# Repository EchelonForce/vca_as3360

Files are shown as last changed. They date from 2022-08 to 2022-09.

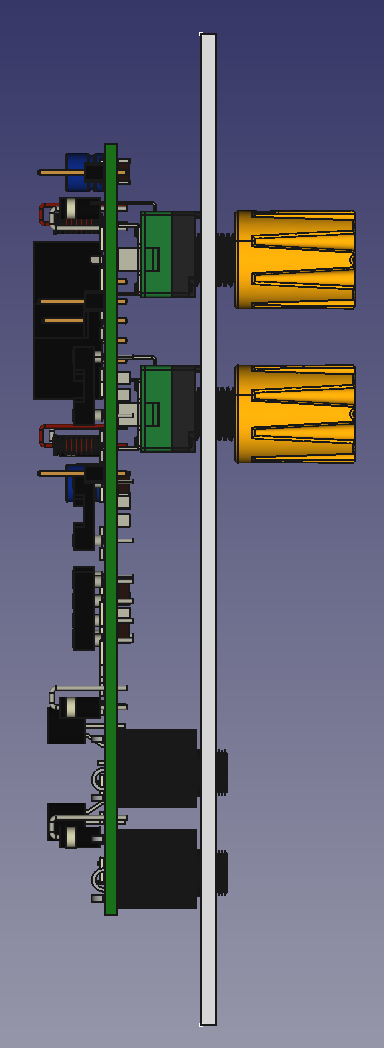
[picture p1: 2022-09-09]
front_panel_v1/render3.png

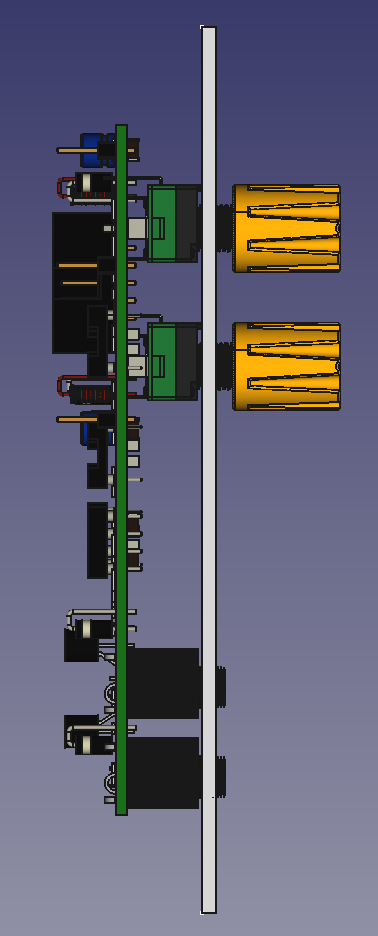
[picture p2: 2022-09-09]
dual_front_panel_v1/render3.png

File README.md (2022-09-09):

# Eurorack VCA AS3360

This is a design for a eurorack VCA using the AS3360 Dual VCA chip.

Full writeup here: https://www.robotdialogs.com/2022/09/eurorack-vca-module-as3360.html

This work is licensed under a Creative Commons Attribution-NonCommercial-ShareAlike 4.0 International License. https://creativecommons.org/licenses/by-nc-sa/4.0/

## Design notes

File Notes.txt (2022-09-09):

Useful reference
https://www.lookmumnocomputer.com/1181-dual-vca
http://www.alfarzpp.lv/eng/sc/AS3360.pdf

v1 testing
First build: 
CV a little off:
  pots seem to exercise full range but a lot of the pot range is wasted?
  CV 0-5V instead of 0-10V?
  measured at the pin on the as3360, the CV 0-10 goes 0-2V as designed, but the data sheet has max gain listed at 1.7-1.8V, so 2V is a bit too high. Need to adjust dividers into U3 because the non-inverting buffer has gain of 2 I didn't account for...I think I want about 1.6V at the AS3360 so I'll shoot for 0.8V at the input of U3, so 390k/33k...looks good.

v1 to v2 changes
used 33k instead of 50k
used 390k instead of 400k
U3 is label tl074 but it should be lm358, swapped with U1 which is also wrong.

May need to swap for smd tl072's

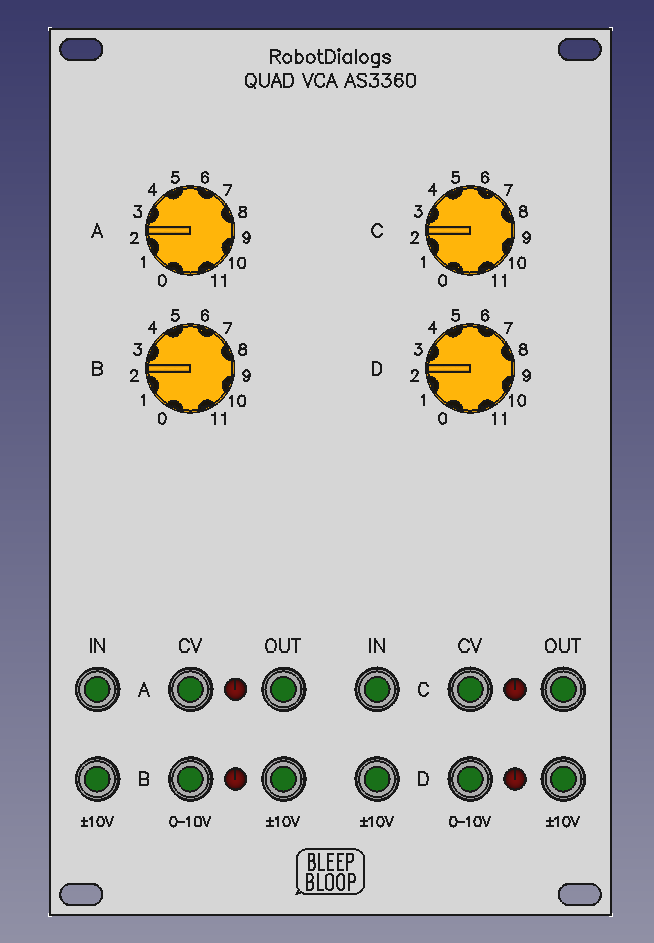
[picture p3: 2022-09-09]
dual_front_panel_v1/render1.png

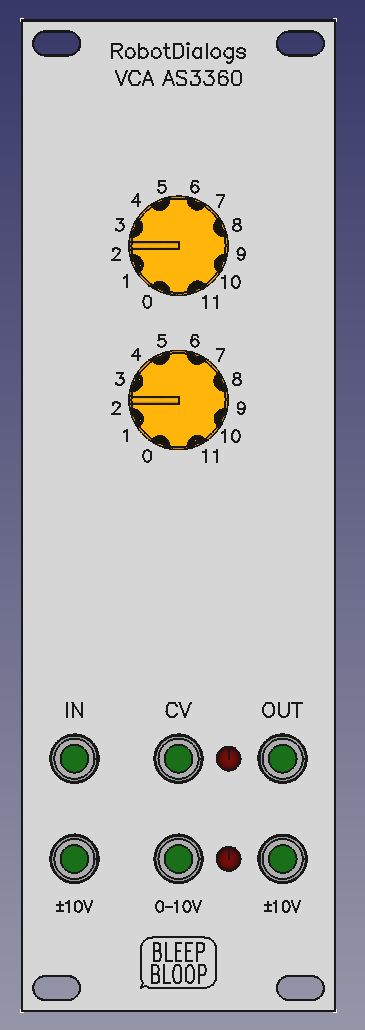
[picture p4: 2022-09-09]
front_panel_v1/render1.png

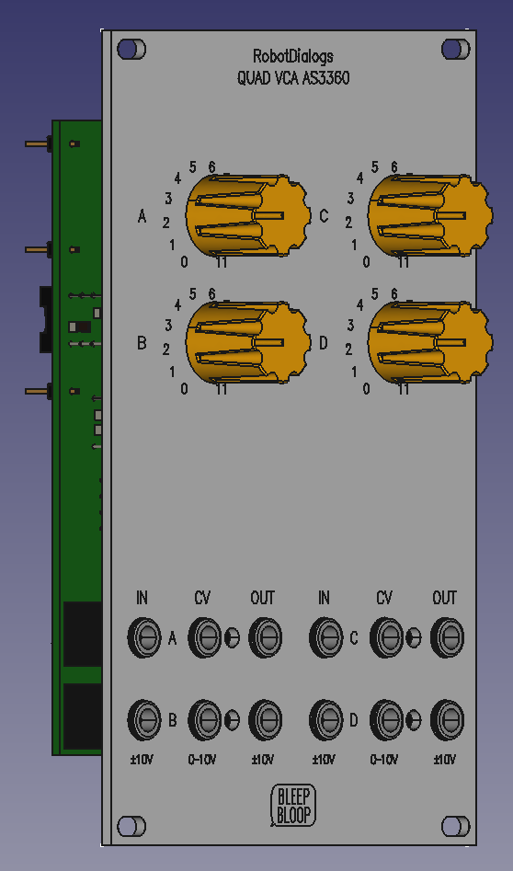
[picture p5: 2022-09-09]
dual_front_panel_v1/render2.png

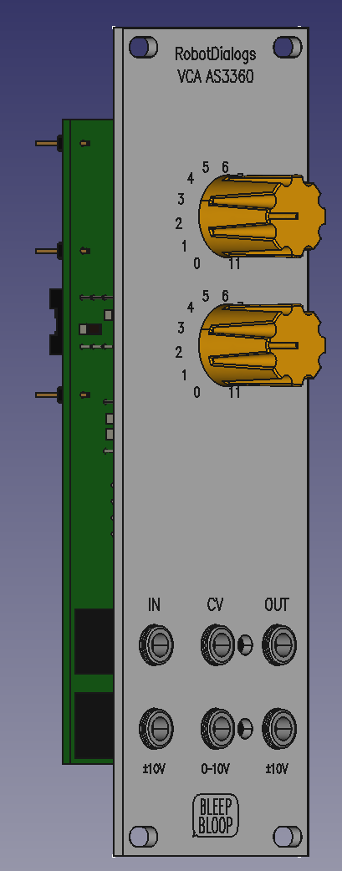
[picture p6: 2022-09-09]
front_panel_v1/render2.png

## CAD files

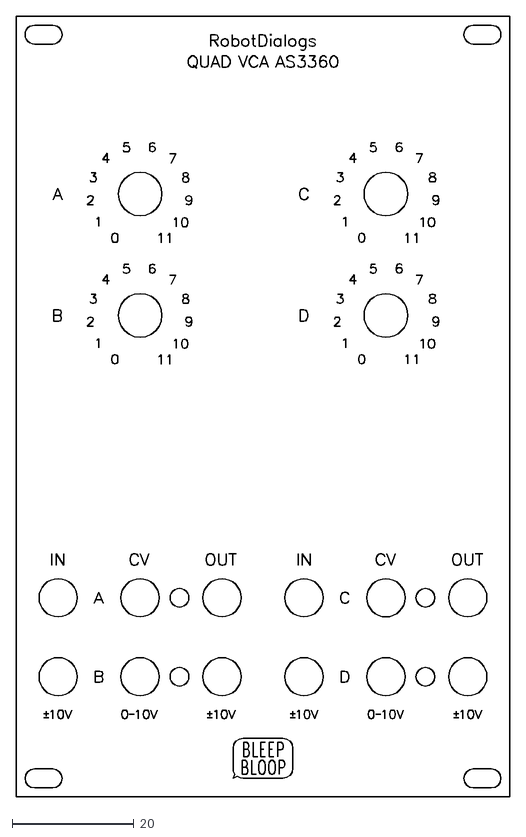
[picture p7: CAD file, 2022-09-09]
dual_front_panel_v1/dual_vca_as3360_v1_front_panel_v1_engraving.dxf
81.2 x 128.4

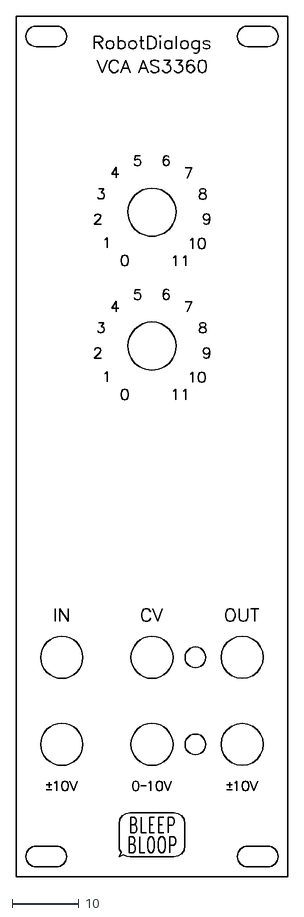
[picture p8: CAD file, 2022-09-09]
front_panel_v1/vca_as3360_v1_front_panel_v1_engraving.dxf
40.5 x 128.4

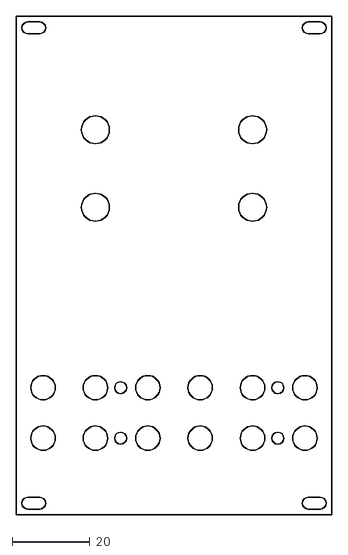
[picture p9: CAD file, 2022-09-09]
dual_front_panel_v1/dual_vca_as3360_v1_front_panel_v1_no_engraving.dxf
81.3 x 128.5

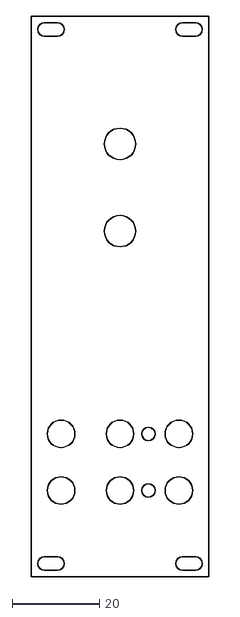
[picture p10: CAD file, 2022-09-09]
front_panel_v1/vca_as3360_v1_front_panel_v1_no_engraving.dxf
40.6 x 128.5

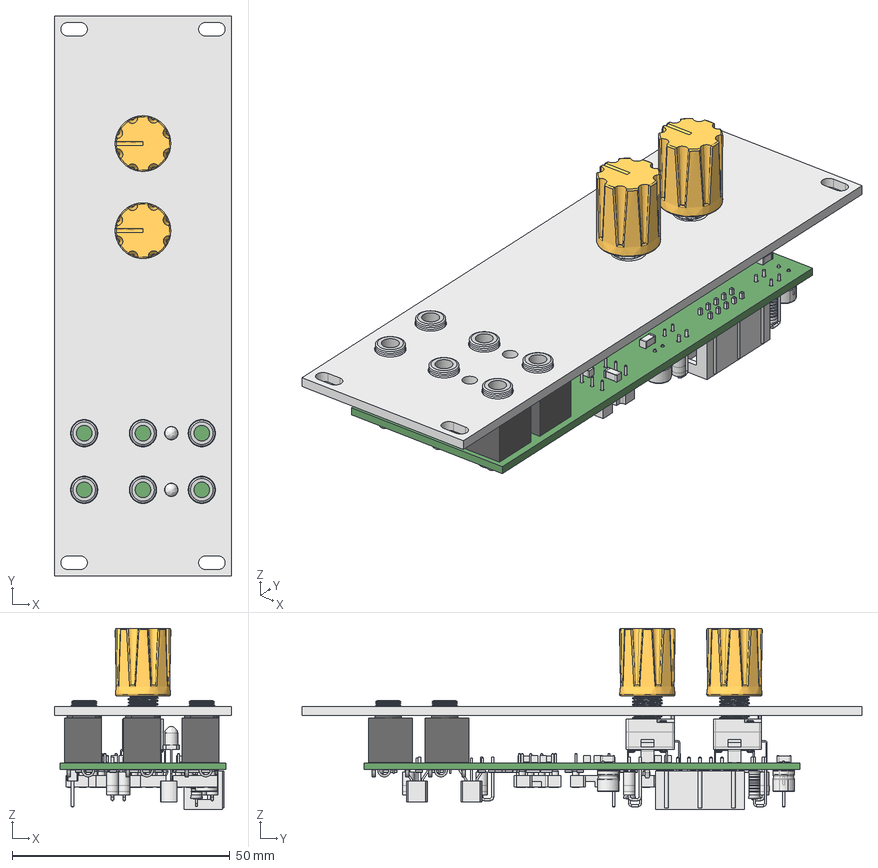
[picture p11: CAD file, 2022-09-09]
front_panel_v1/vca_as3360_v1_front_panel_v1.FCStd
40.6 x 128.5 x 41.6 mm
vca_as3360_v1 PCB

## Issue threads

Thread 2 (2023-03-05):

opamps and diodes confusion

KeLaiFu, 2023-03-05:
I've been working with your schematic and layout to build a smaller 4HP version, and just noticed a few things from your notes which I am unsure about.
Firstly, you mention the opamps being mixed up in V1. I am a little unsure if this means I need to switch them around as there only appears to be a v1, so could you clarify which of the 3 should be a 358?

Second, any suggestions for the diode value needed for D1/2/3/4

EchelonForce, 2023-03-05:
The v1 schematic is the only one for now, I usually take notes in anticipation of a v2, so it typically says changes for v2 even when I haven't started a v2.

The schematic is correct with regard to the op-amps. The problem I noted was that the labels I added on the PCB's silkscreen were placed next to the wrong footprints, realistically the TL072 and LM358 are pretty interchangeable in this. I usually use LM358s on CV inputs and TL07x's on audio pathways.

I used 1N4001's for the diodes D2,D3,D4,D6 (and generic red LEDs for D1/D5).

I recently built a bunch of these and have reduced R19 and R20 to 24k, and left R29 and R24 as 333k as in the notes. This reduced clipping and improved the knob range, the allowed voltage on the Linear CV pin on the AS3360 is larger than the input one should use in practice. I think mine ended up somewhere around 0:1.8V input (at the chip) for full range.

KeLaiFu, 2023-03-06:
Thanks for the reply. I have changed the layout to SMD, so the silkscreen issues won't effect me. Glad the 400k resistors won't be needed too, it was one of the few values I don't have in my stash and after ordering some, I received 402k anyway so fingers crossed I have some 333k.

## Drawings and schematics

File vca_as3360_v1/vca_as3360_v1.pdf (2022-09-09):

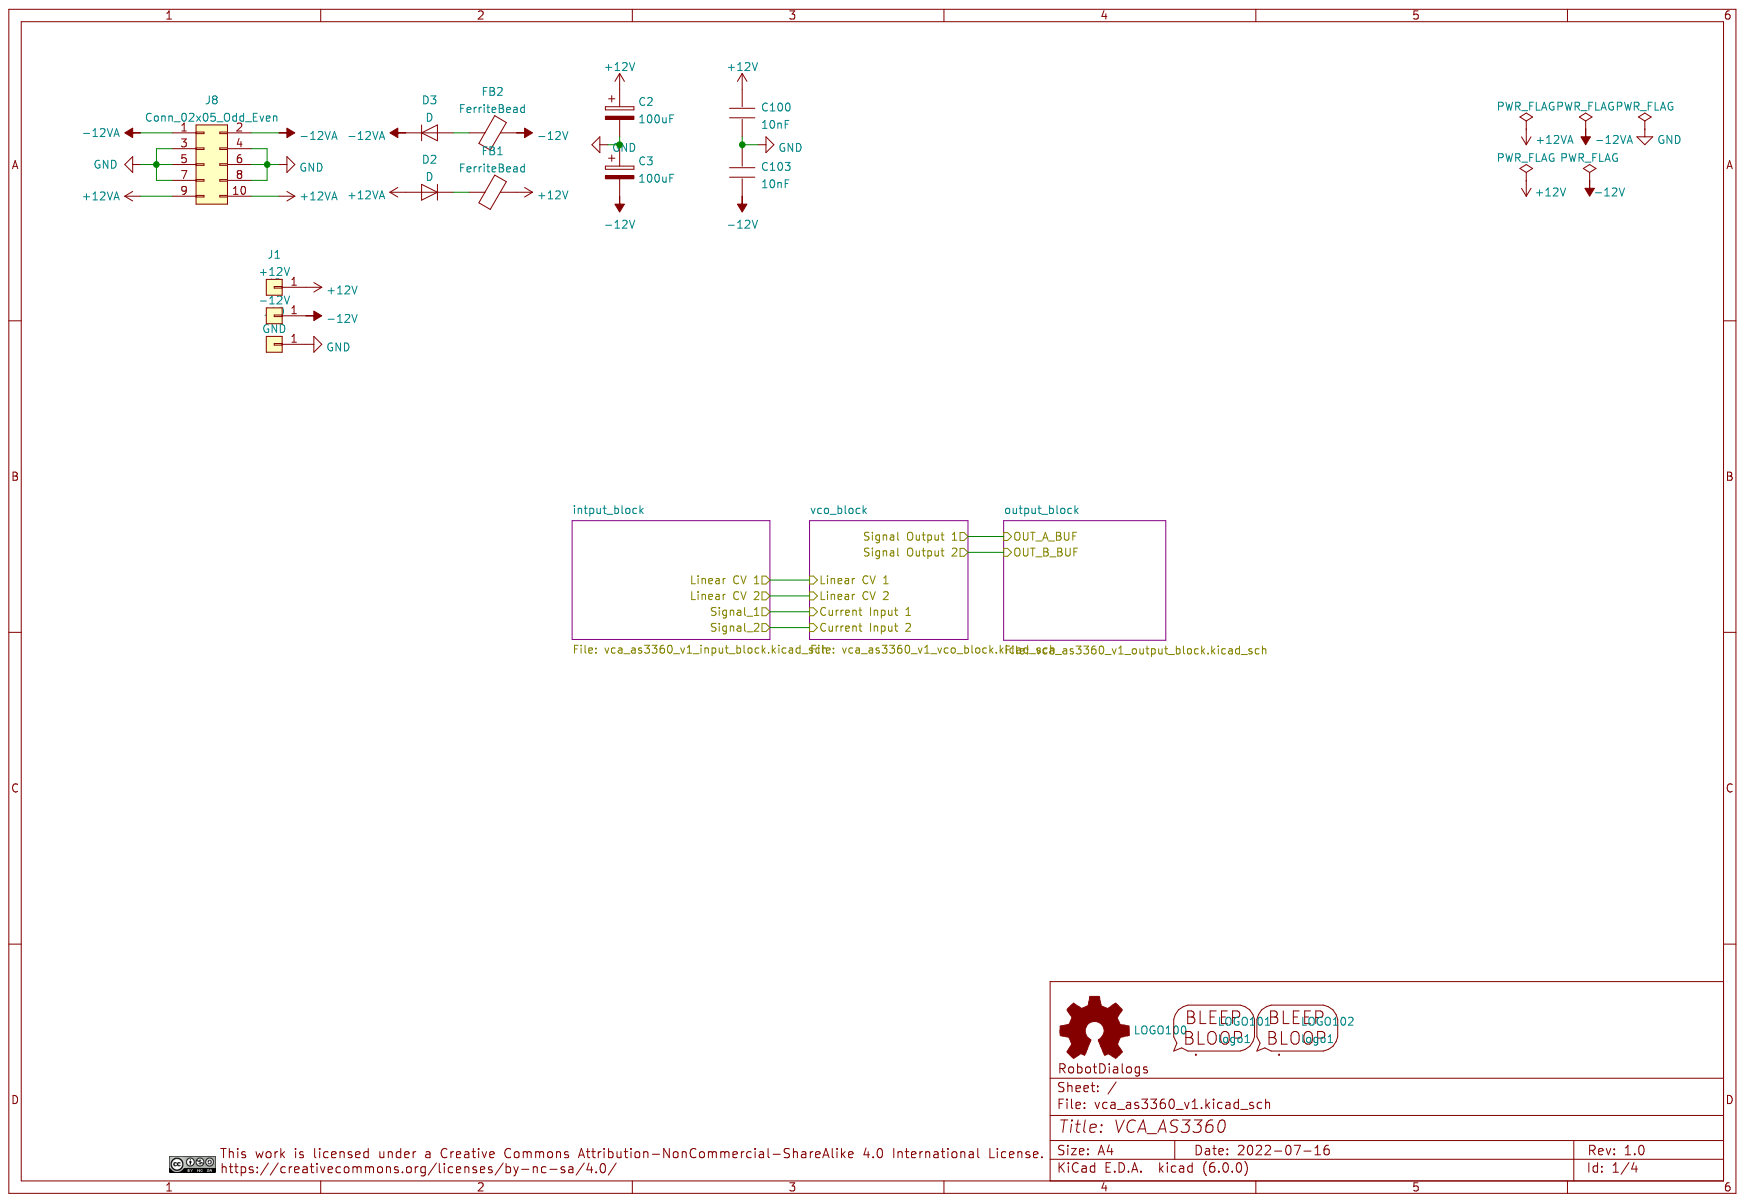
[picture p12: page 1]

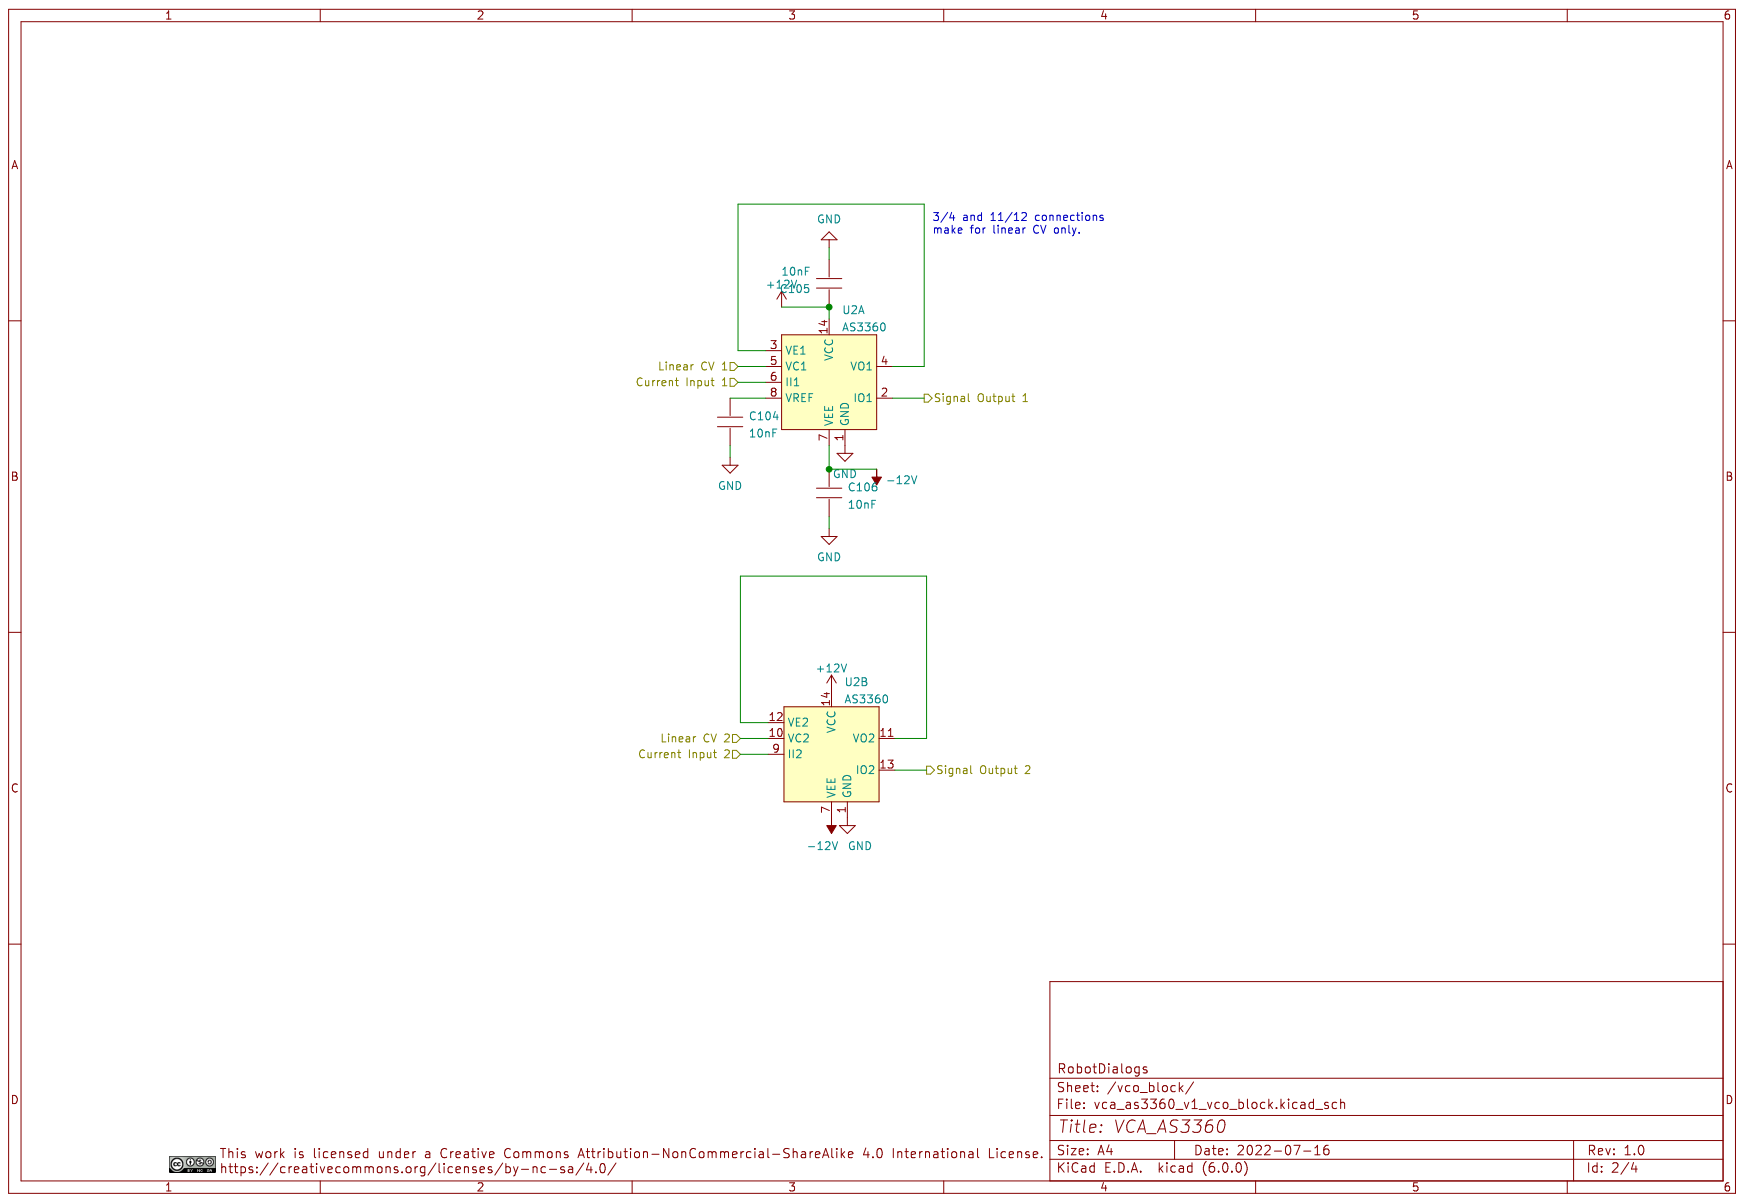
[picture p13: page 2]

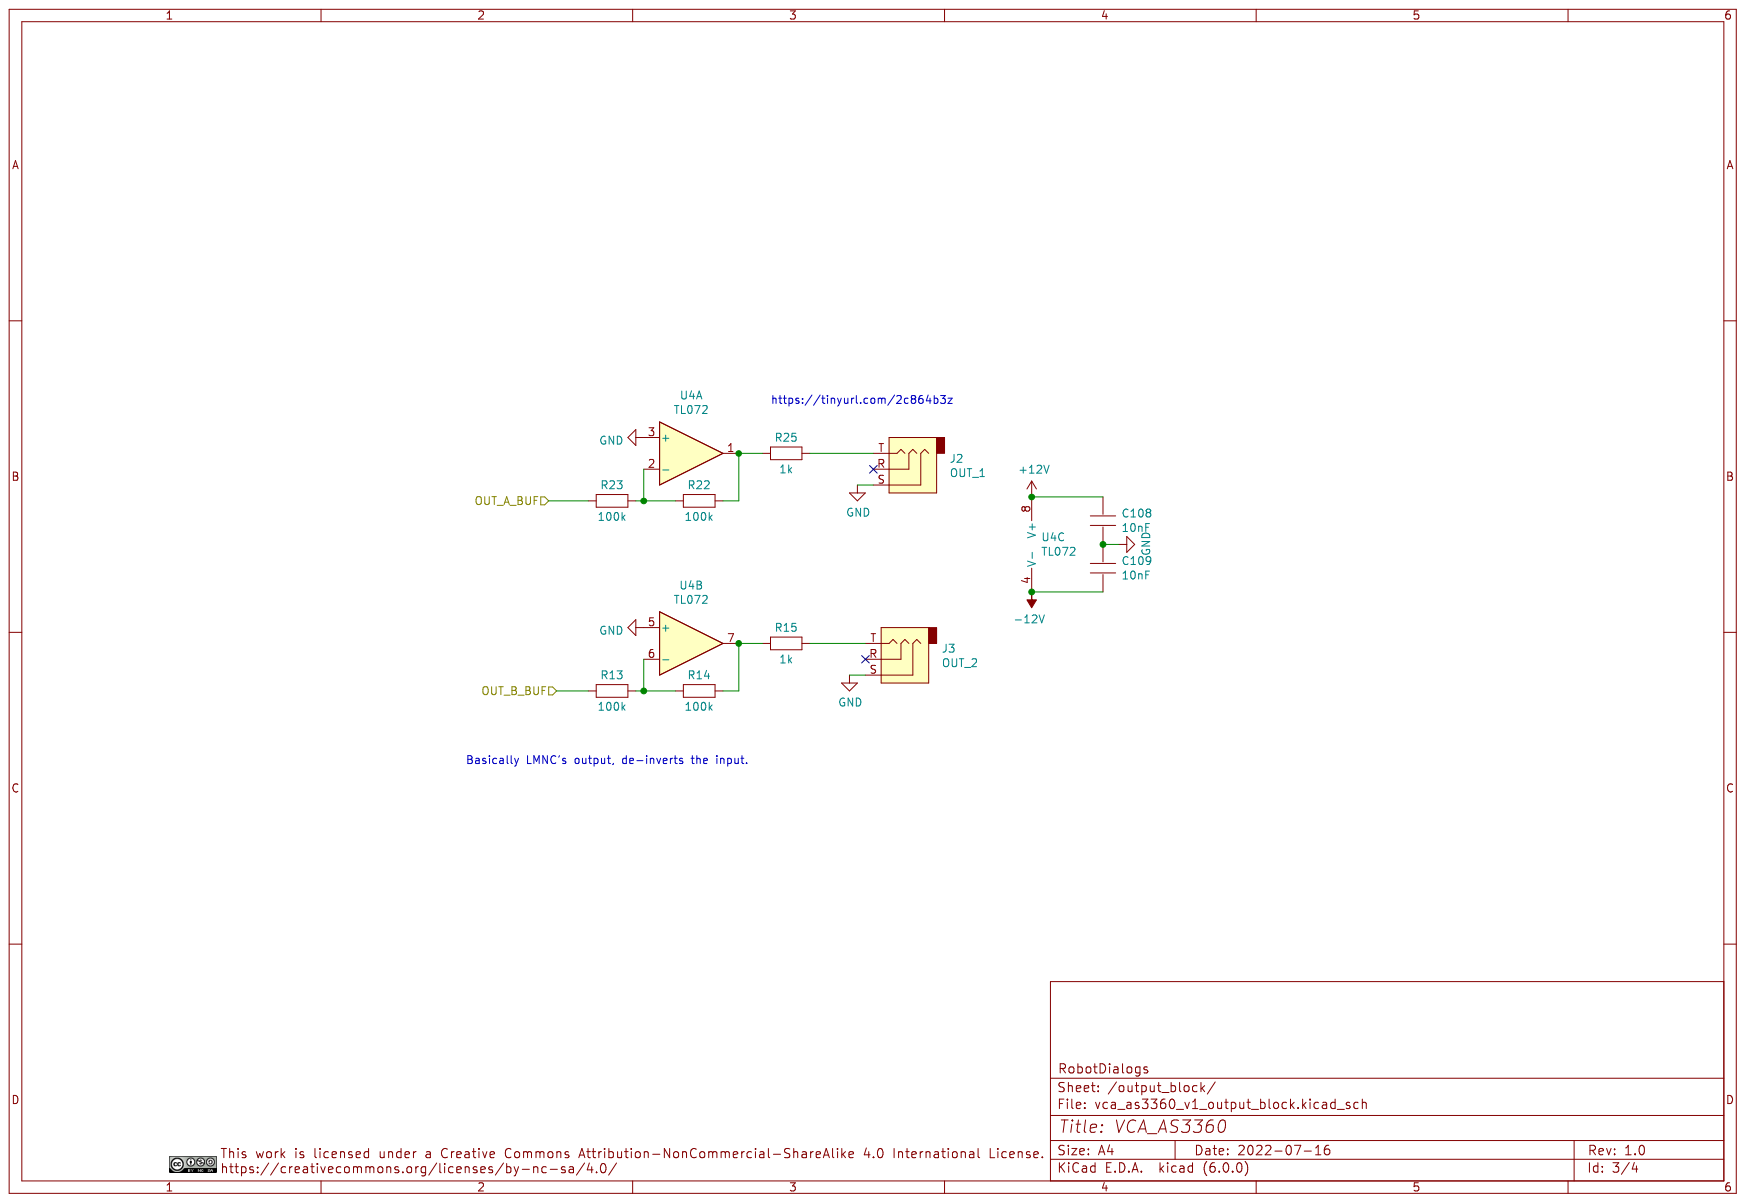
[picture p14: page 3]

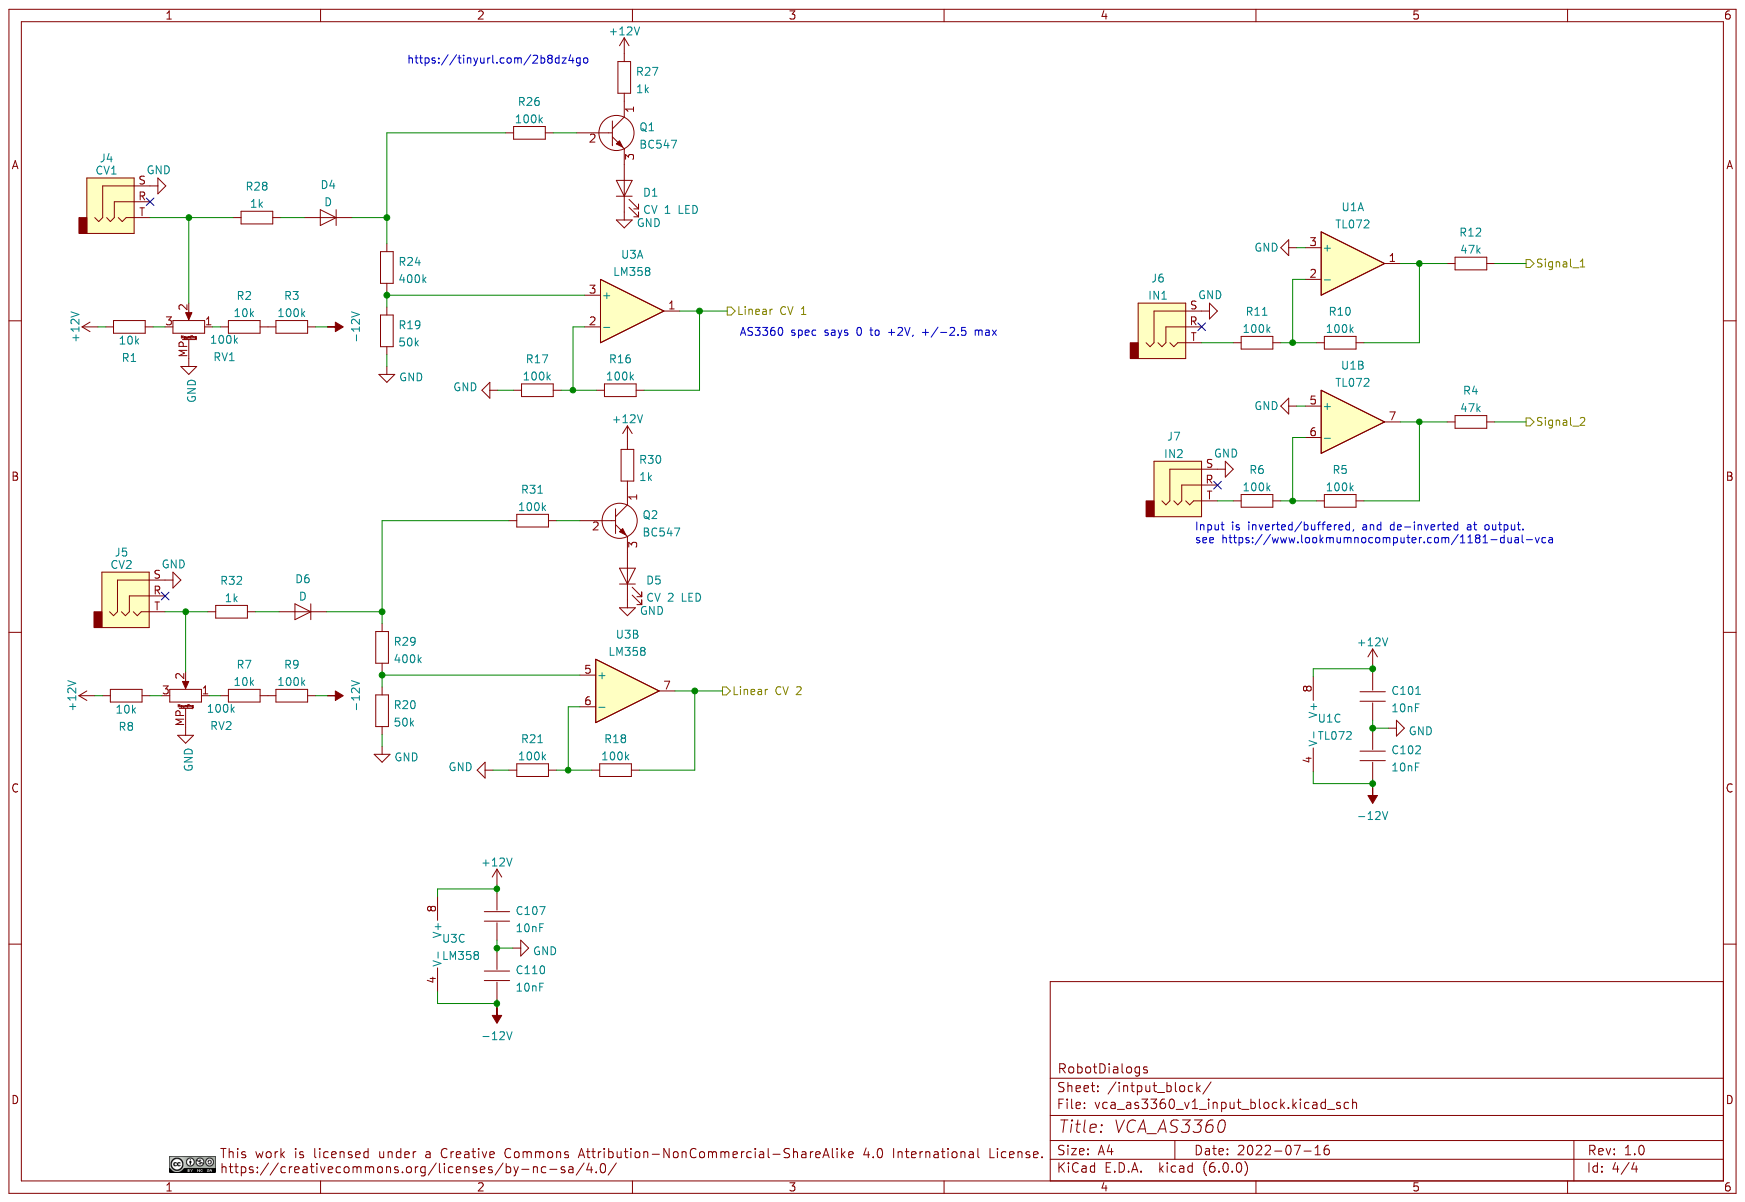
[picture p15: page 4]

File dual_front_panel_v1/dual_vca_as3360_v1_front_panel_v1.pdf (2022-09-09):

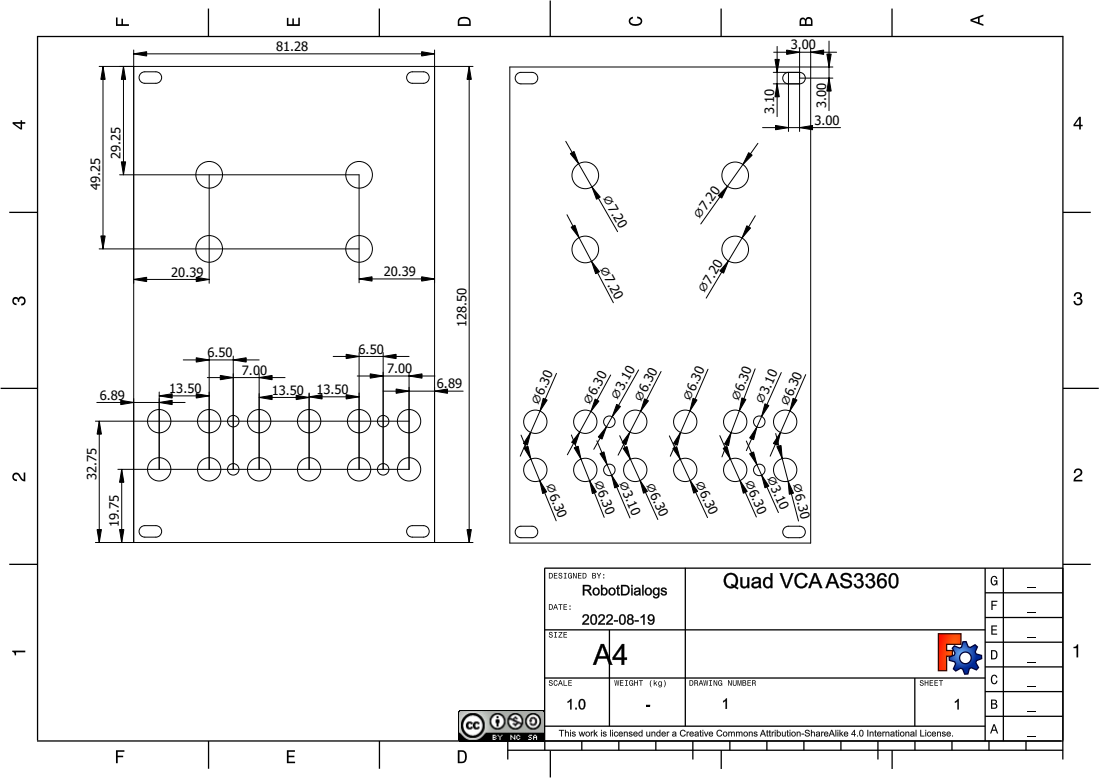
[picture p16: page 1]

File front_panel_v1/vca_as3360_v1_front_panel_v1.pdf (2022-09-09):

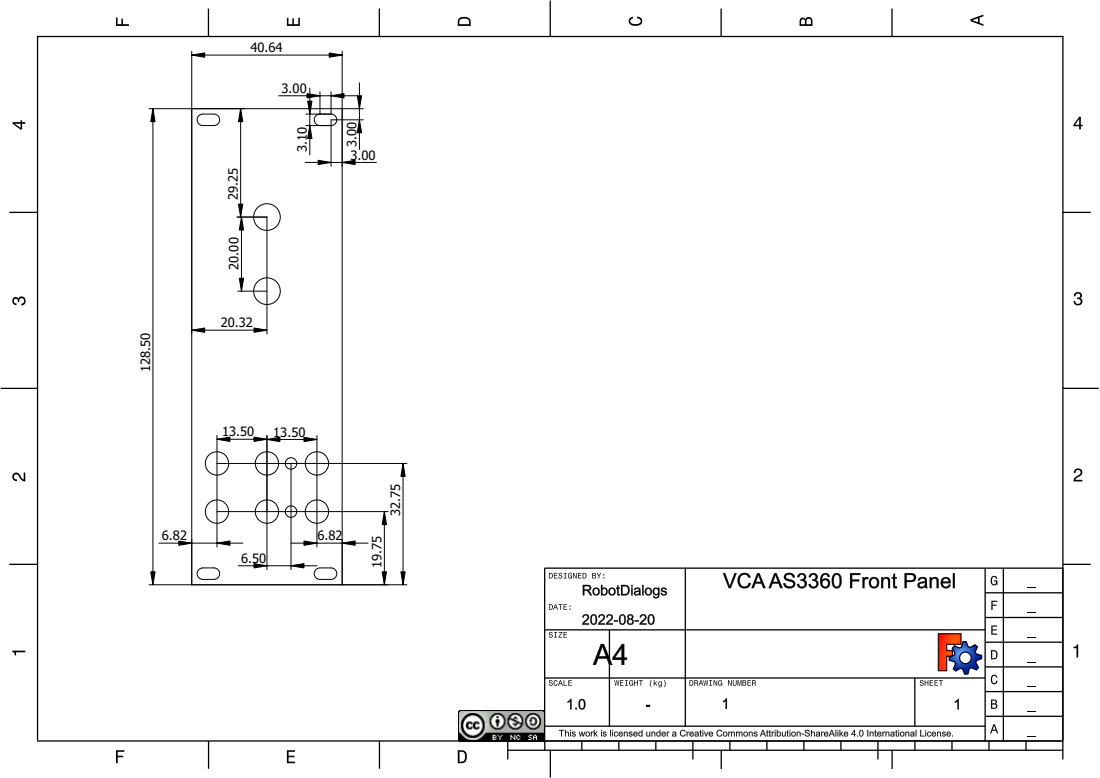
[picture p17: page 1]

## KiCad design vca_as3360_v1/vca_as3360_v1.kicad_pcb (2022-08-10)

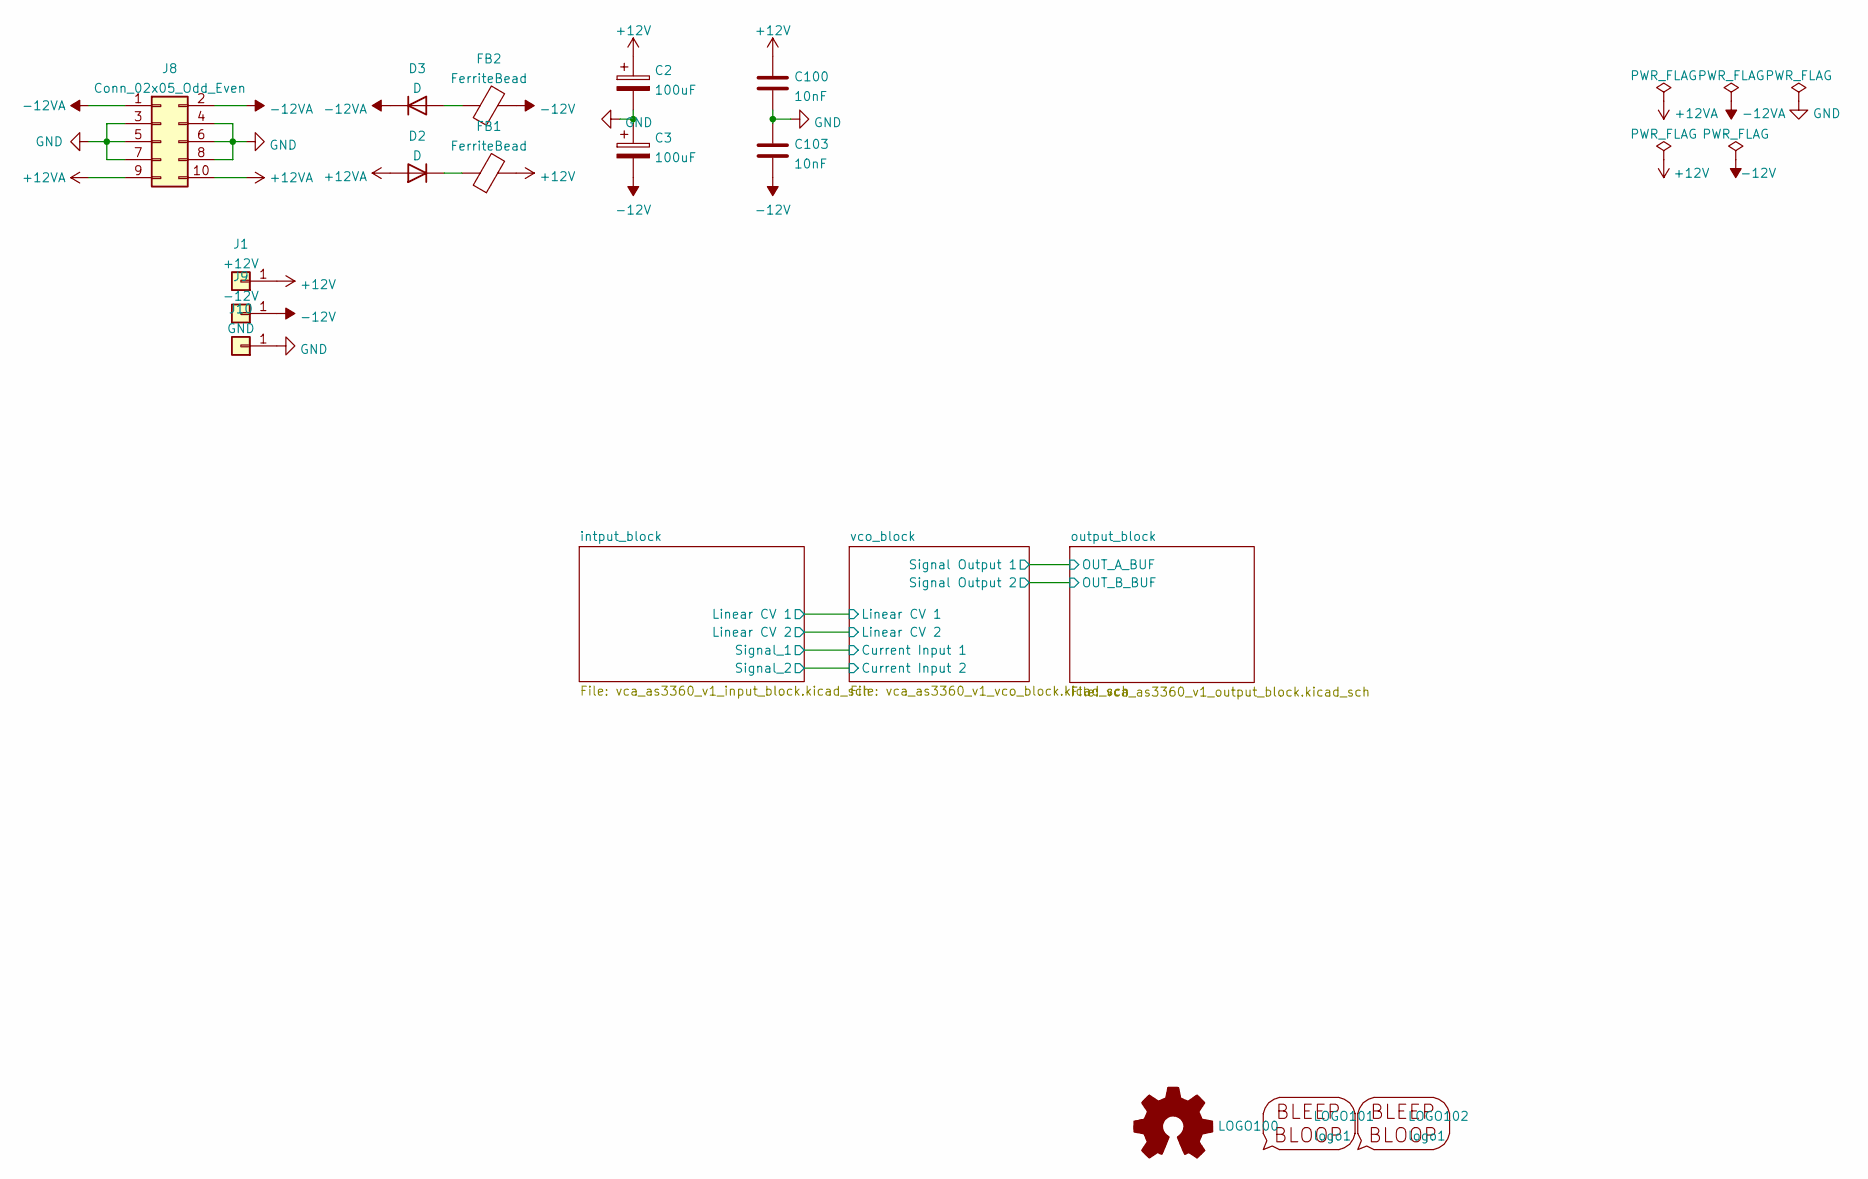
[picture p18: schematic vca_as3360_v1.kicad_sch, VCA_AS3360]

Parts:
C2, C3: 100uF; CP_Radial_D5.0mm_P2.50mm
C100, C103: 10nF; C_1206_3216Metric_Pad1.33x1.80mm_HandSolder
D2, D3: D; D_A-405_P2.54mm_Vertical_KathodeUp
FB1, FB2: FerriteBead; L_Axial_L6.6mm_D2.7mm_P2.54mm_Vertical_Vishay_IM-2
J1: +12V; PinHeader_1x01_P2.54mm_Vertical
J8: Conn_02x05_Odd_Even; IDC-Header_2x05_P2.54mm_Vertical
J9: -12V; PinHeader_1x01_P2.54mm_Vertical
J10: GND; PinHeader_1x01_P2.54mm_Vertical
LOGO100: Logo_Open_Hardware_Small; OSHW-Symbol_6.7x6mm_SilkScreen
LOGO101: logo1; Logo1
LOGO102: logo1; Logo2

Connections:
+12V: C2.1, C100.1, FB1.2, J1.1; also elsewhere on the board
+12VA: D2.2 (A), J8.9, J8.10
-12V: C3.2, C103.2, FB2.2, J9.1; also elsewhere on the board
-12VA: D3.1 (K), J8.1, J8.2
GND: C2.2, C3.1, C100.2, C103.1, J8.3, J8.4, J8.5, J8.6, J8.7, J8.8, J10.1; also elsewhere on the board
unnamed: D2.1 (K), FB1.1
unnamed: D3.2 (A), FB2.1

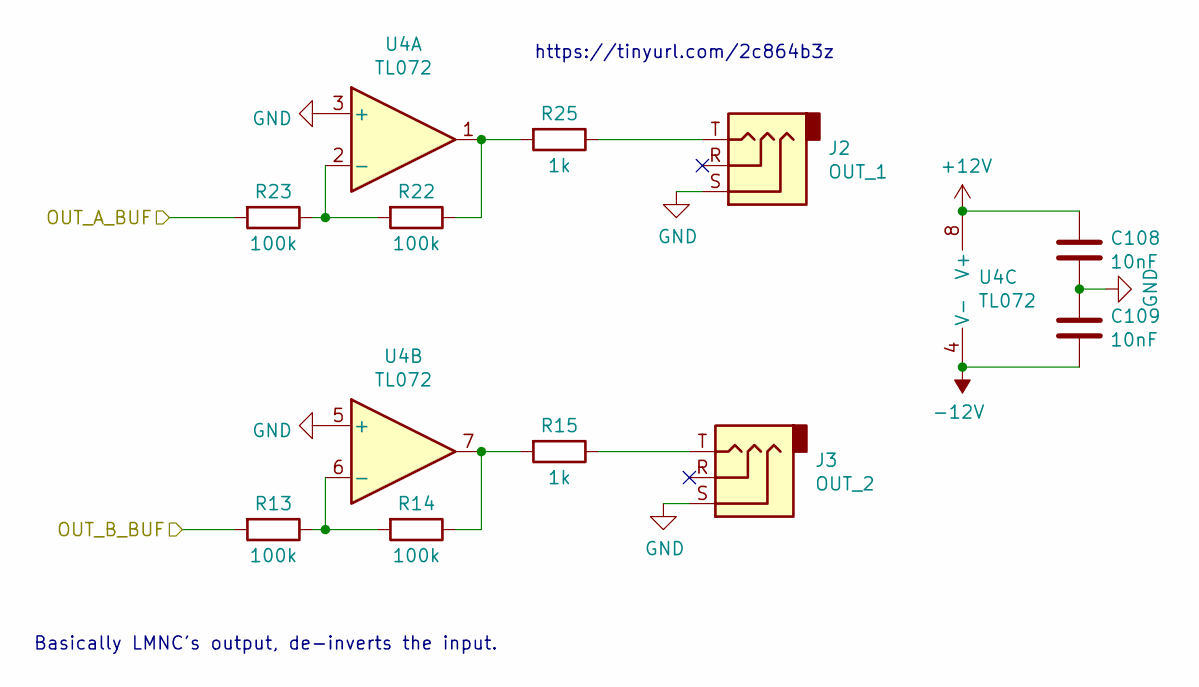
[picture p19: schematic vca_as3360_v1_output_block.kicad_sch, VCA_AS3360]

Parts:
C108, C109: 10nF; C_1206_3216Metric_Pad1.33x1.80mm_HandSolder
J2: OUT_1; Jack_3.5mm_MJ-355W_Vertical
J3: OUT_2; Jack_3.5mm_MJ-355W_Vertical
R13, R14, R22, R23: 100k; R_1206_3216Metric_Pad1.30x1.75mm_HandSolder
R15, R25: 1k; R_1206_3216Metric_Pad1.30x1.75mm_HandSolder
U4: TL072; DIP-8_W7.62mm_Socket_LongPads

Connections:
+12V: C108.2, U4.8 (V+); also elsewhere on the board
-12V: C109.1, U4.4 (V-); also elsewhere on the board
/output_block/OUT_A_BUF: R23.2; also elsewhere on the board
/output_block/OUT_B_BUF: R13.2; also elsewhere on the board
GND: C108.1, C109.2, J2.S, J3.S, U4.3 (+), U4.5 (+); also elsewhere on the board
unnamed: J2.T, R25.1
unnamed: J3.T, R15.1
unnamed: R14.1, R15.2, U4.7
unnamed: R13.1, R14.2, U4.6 (-)
unnamed: R22.2, R23.1, U4.2 (-)
unnamed: R22.1, R25.2, U4.1

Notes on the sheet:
Basically LMNC's output, de-inverts the input.
https://tinyurl.com/2c864b3z

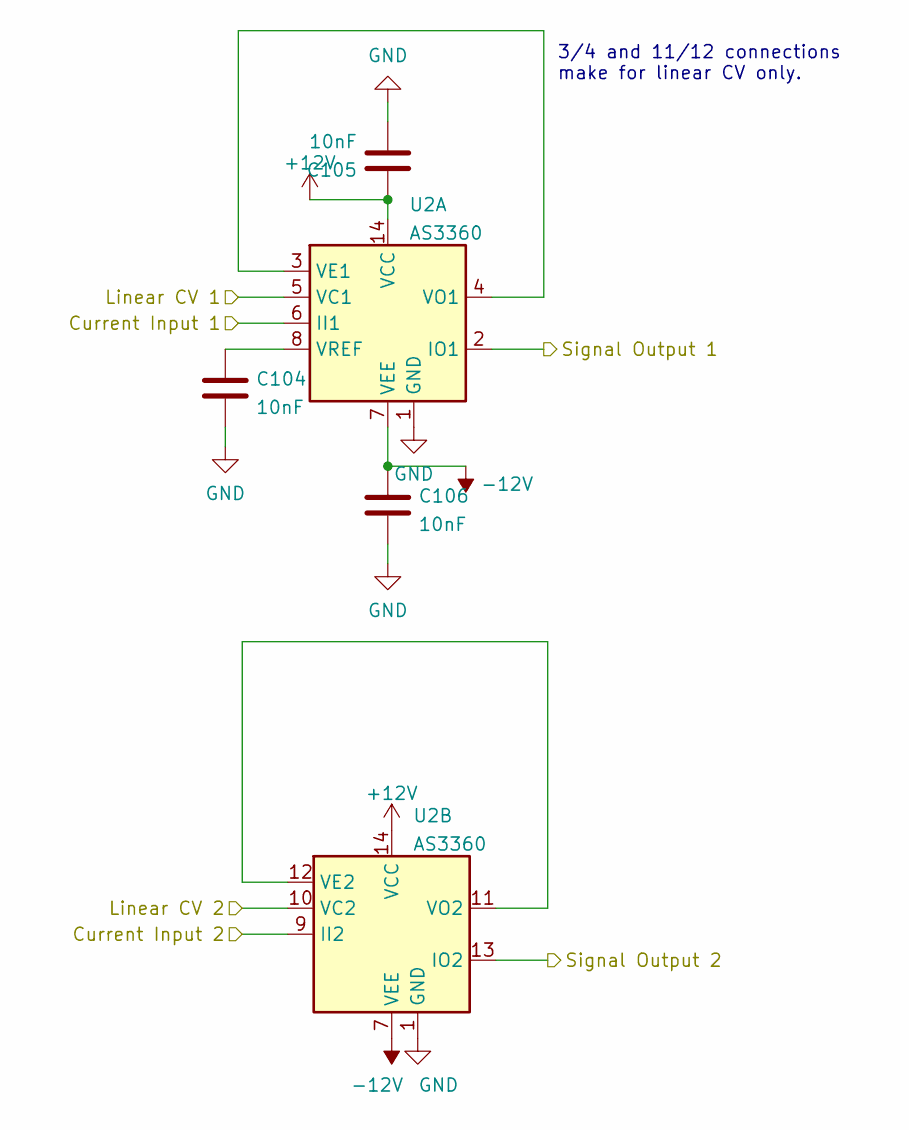
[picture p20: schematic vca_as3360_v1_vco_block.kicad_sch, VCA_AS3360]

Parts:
C104, C105, C106: 10nF; C_1206_3216Metric_Pad1.33x1.80mm_HandSolder
U2: AS3360; DIP-14_W7.62mm_Socket_LongPads

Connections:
+12V: C105.1, U2.14 (VCC); also elsewhere on the board
-12V: C106.1, U2.7 (VEE); also elsewhere on the board
/intput_block/Linear CV 1: U2.5 (VC1); also elsewhere on the board
/intput_block/Linear CV 2: U2.10 (VC2); also elsewhere on the board
/intput_block/Signal_1: U2.6 (II1); also elsewhere on the board
/intput_block/Signal_2: U2.9 (II2); also elsewhere on the board
/output_block/OUT_A_BUF: U2.2 (IO1); also elsewhere on the board
/output_block/OUT_B_BUF: U2.13 (IO2); also elsewhere on the board
GND: C104.2, C105.2, C106.2, U2.1 (GND); also elsewhere on the board
unnamed: C104.1, U2.8 (VREF)
unnamed: U2.3 (VE1), U2.4 (VO1)
unnamed: U2.11 (VO2), U2.12 (VE2)

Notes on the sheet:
3/4 and 11/12 connections make for linear CV only.

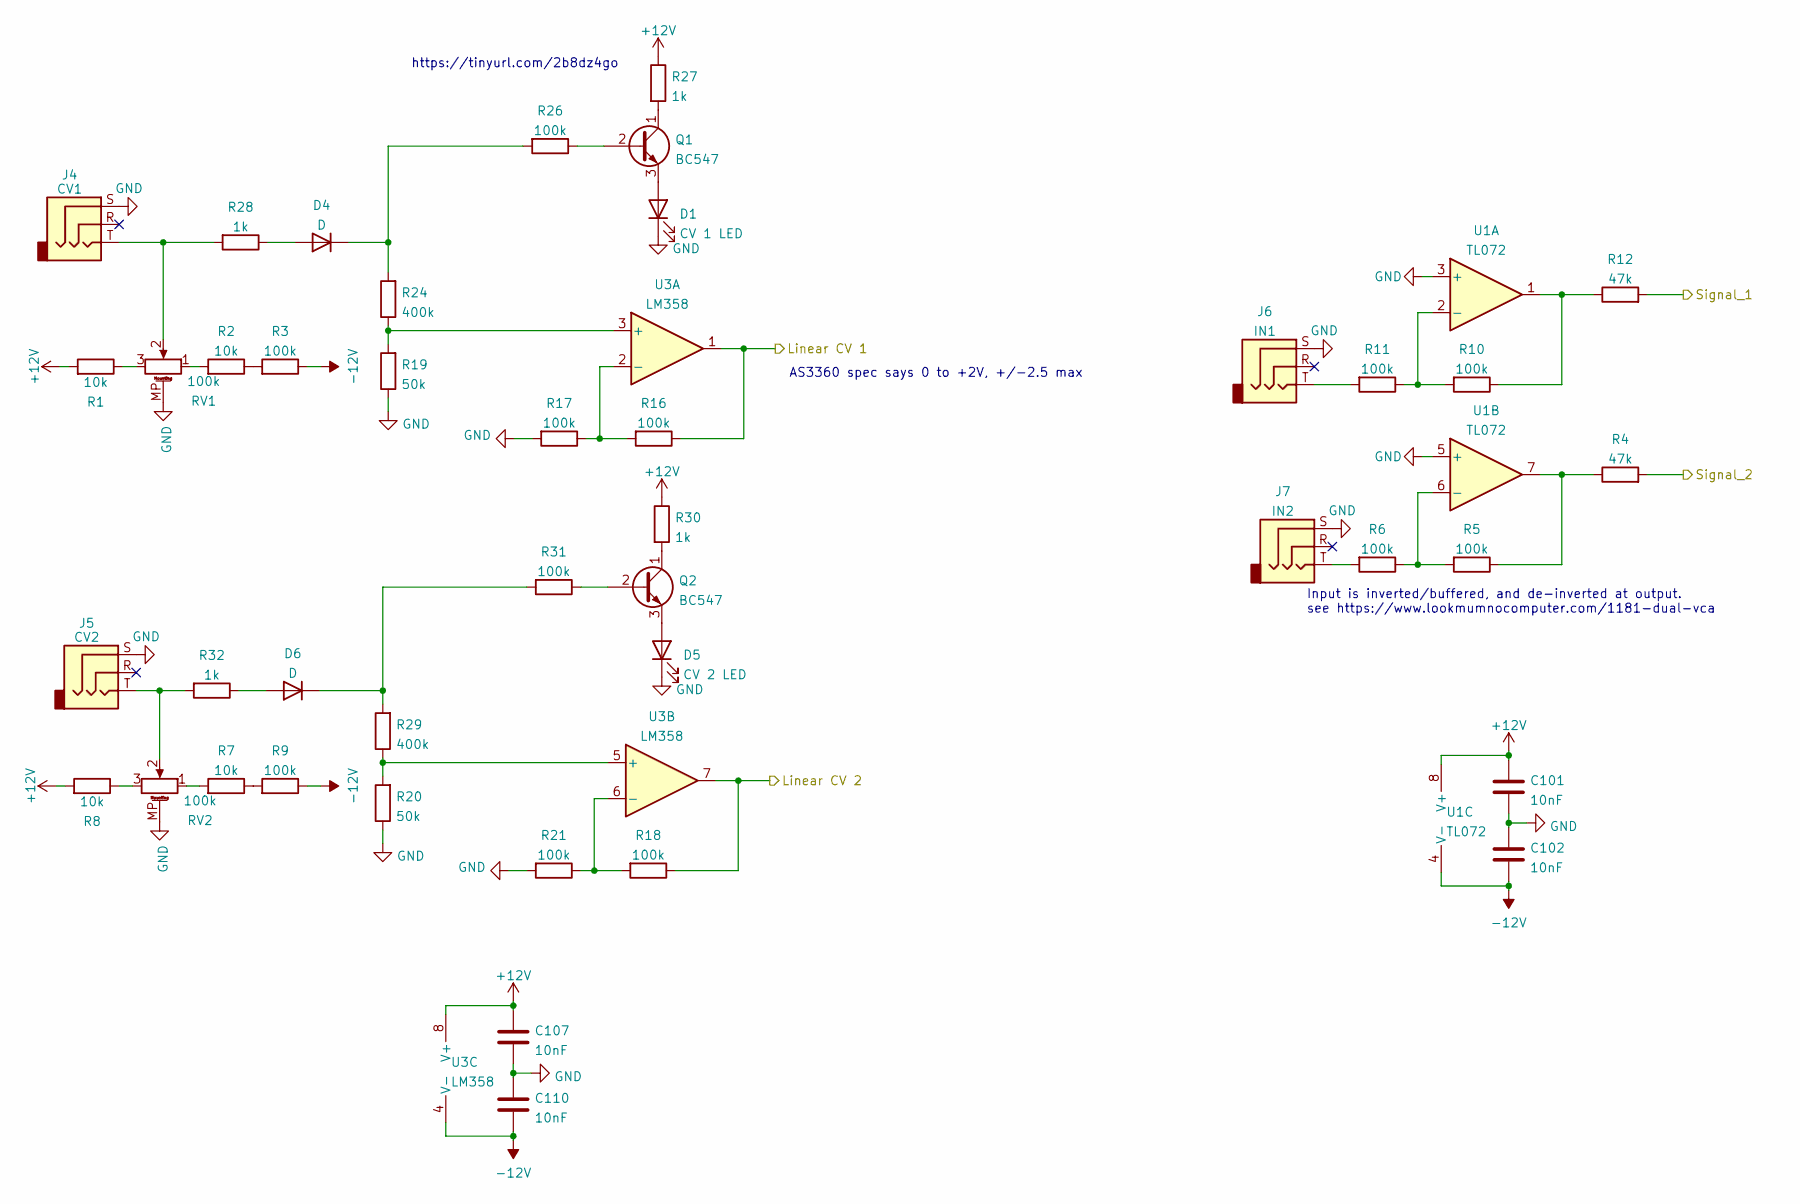
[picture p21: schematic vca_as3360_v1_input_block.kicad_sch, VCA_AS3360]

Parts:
C101, C102, C107, C110: 10nF; C_1206_3216Metric_Pad1.33x1.80mm_HandSolder
D1: CV 1 LED; LED_D3.0mm
D4, D6: D; D_A-405_P2.54mm_Vertical_KathodeUp
D5: CV 2 LED; LED_D3.0mm
J4: CV1; Jack_3.5mm_MJ-355W_Vertical
J5: CV2; Jack_3.5mm_MJ-355W_Vertical
J6: IN1; Jack_3.5mm_MJ-355W_Vertical
J7: IN2; Jack_3.5mm_MJ-355W_Vertical
Q1, Q2: BC547; TO-92_Inline_Wide
R1, R2, R7, R8: 10k; R_1206_3216Metric_Pad1.30x1.75mm_HandSolder
R3, R5, R6, R9, R10, R11, R16, R17, R18, R21, R26, R31: 100k; R_1206_3216Metric_Pad1.30x1.75mm_HandSolder
R4, R12: 47k; R_1206_3216Metric_Pad1.30x1.75mm_HandSolder
R19, R20: 50k; R_1206_3216Metric_Pad1.30x1.75mm_HandSolder
R24, R29: 400k; R_1206_3216Metric_Pad1.30x1.75mm_HandSolder
R27, R28, R30, R32: 1k; R_1206_3216Metric_Pad1.30x1.75mm_HandSolder
RV1, RV2: 100k; Potentiometer_Alpha_RD901F-40-00D_Single_Vertical_w_3d
U1: TL072; DIP-8_W7.62mm_Socket_LongPads
U3: LM358; DIP-8_W7.62mm_Socket_LongPads

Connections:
+12V: C101.1, C107.1, R1.2, R8.2, R27.1, R30.1, U1.8 (V+), U3.8 (V+); also elsewhere on the board
-12V: C102.2, C110.2, R3.1, R9.1, U1.4 (V-), U3.4 (V-); also elsewhere on the board
/intput_block/Linear CV 1: R16.1, U3.1; also elsewhere on the board
/intput_block/Linear CV 2: R18.1, U3.7; also elsewhere on the board
/intput_block/Signal_1: R12.2; also elsewhere on the board
/intput_block/Signal_2: R4.2; also elsewhere on the board
GND: C101.2, C102.1, C107.2, C110.1, D1.1 (K), D5.1 (K), J4.S, J5.S, J6.S, J7.S, R17.2, R19.1, R20.1, R21.2, RV1.MP (MountPin), RV2.MP (MountPin), U1.3 (+), U1.5 (+); also elsewhere on the board
unnamed: D1.2 (A), Q1.3 (E)
unnamed: D4.1 (K), R24.2, R26.2
unnamed: D4.2 (A), R28.1
unnamed: D5.2 (A), Q2.3 (E)
unnamed: D6.1 (K), R29.2, R31.2
unnamed: D6.2 (A), R32.1
unnamed: J4.T, R28.2, RV1.2
unnamed: J5.T, R32.2, RV2.2
unnamed: J6.T, R11.2
unnamed: J7.T, R6.2
unnamed: Q1.1 (C), R27.2
unnamed: Q1.2 (B), R26.1
unnamed: Q2.1 (C), R30.2
unnamed: Q2.2 (B), R31.1
unnamed: R1.1, RV1.3
unnamed: R2.2, RV1.1
unnamed: R2.1, R3.2
unnamed: R4.1, R5.1, U1.7
unnamed: R5.2, R6.1, U1.6 (-)
unnamed: R7.1, R9.2
unnamed: R7.2, RV2.1
unnamed: R8.1, RV2.3
unnamed: R10.2, R11.1, U1.2 (-)
unnamed: R10.1, R12.1, U1.1
unnamed: R16.2, R17.1, U3.2 (-)
unnamed: R18.2, R21.1, U3.6 (-)
unnamed: R19.2, R24.1, U3.3 (+)
unnamed: R20.2, R29.1, U3.5 (+)

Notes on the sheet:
Input is inverted/buffered, and de-inverted at output. see https://www.lookmumnocomputer.com/1181-dual-vca
AS3360 spec says 0 to +2V, +/-2.5 max
https://tinyurl.com/2b8dz4go

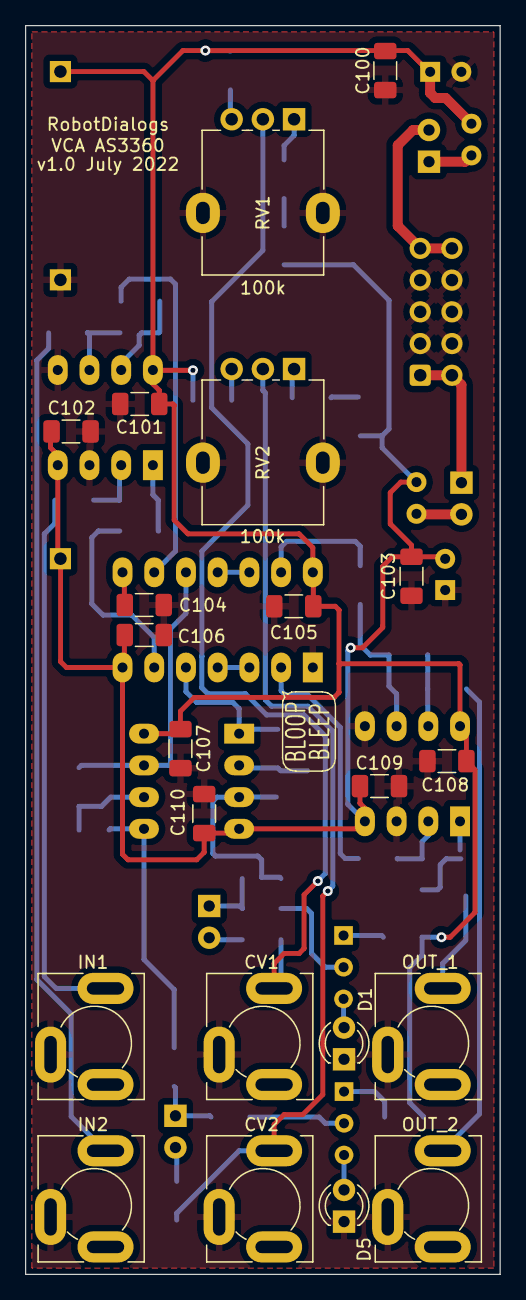
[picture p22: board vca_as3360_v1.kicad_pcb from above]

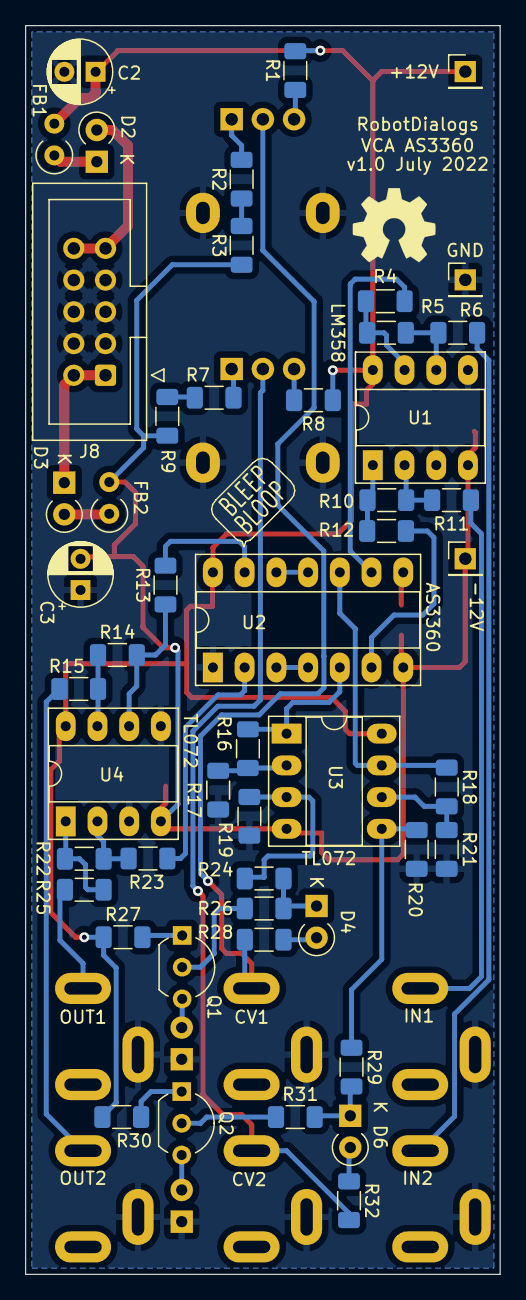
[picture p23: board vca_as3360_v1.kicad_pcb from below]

Board: 2 copper layers, 38.0 x 100.0 mm, 74 parts (51 on the bottom side), 50 nets.

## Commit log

2022-07-16 Schematic mostly figured out, not yet breadboarded
    [vca_as3360_v1.kicad_pcb, vca_as3360_v1.kicad_sch, vca_as3360_v1_input_block.kicad_sch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]
2022-07-31 Layout and routing first pass done
    [vca_as3360_v1.kicad_pcb, vca_as3360_v1.kicad_sch, vca_as3360_v1_input_block.kicad_sch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]
2022-07-31 Geographic rename and silkscreen cleanup
    [vca_as3360_v1.kicad_pcb, vca_as3360_v1.kicad_sch, vca_as3360_v1_input_block.kicad_sch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]
2022-07-31 Add jumper points for passing power to another pcb
    [vca_as3360_v1.kicad_pcb, vca_as3360_v1.kicad_sch]
2022-08-10 Fix pcb title block
    [vca_as3360_v1.kicad_pcb]
2022-09-09 Add front panel files
    [dual_vca_as3360_v1_front_panel_v1_engraving.dxf, dual_vca_as3360_v1_front_panel_v1_no_engraving.dxf, vca_as3360_v1_front_panel_v1.FCStd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]
2022-09-09 Add readme, notes and schematic pdf
2022-09-09 panelized outputs for v1
    [vca_as3360_v1_panelized.kicad_pcb]
